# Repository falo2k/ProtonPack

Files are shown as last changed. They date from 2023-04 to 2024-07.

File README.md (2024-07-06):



# Teensy Based Proton Pack Electronics
This is my implementation of the electronics for a Ghostbusters Proton Pack.  It uses a Teensy microcontroller in both parts of the kit (Pack and Wand) and communicates between them over 4 wires (power + serial).  For now I have kept it to a simple movie implementation with some additions - overheating and music playback.  I've added two features that are a bit unusual:
- An OLED display in the rear box on the wand is used for managing volume control and track selection, in conjunctions with a rotary encoder (push/turn) in the front knob.
- A [bluetooth receiver](./Images/bluetooth.jpg) can be turned on for playback of anything not available on the SD card.  The module I'm using will mix the stereo audio down to mono for a single pack, but comes as a pair for True Wireless Stereo.  The other board will be in a friend's pack so we can use the packs as a complete speaker set.
  
It is designed to fit inside the 3D printed pack available [here - the Q-Pack](https://github.com/mr-kiou/q-pack).  It's been developed for a Mk3 pack - I will review it at some point in the future for Mk4 compatability.
  
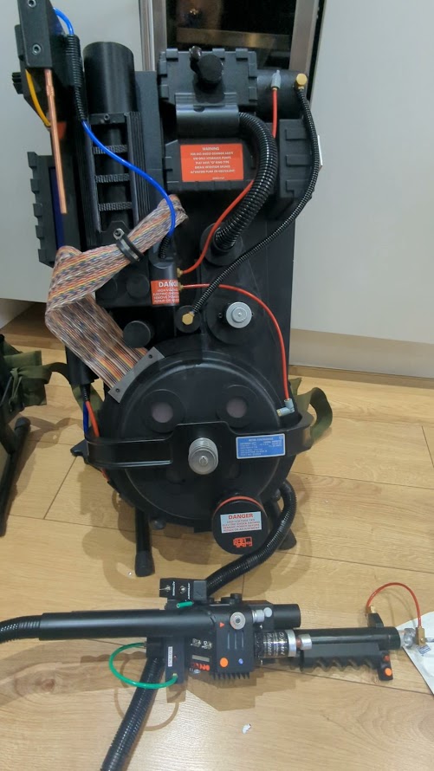
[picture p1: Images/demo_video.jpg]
DEMO VIDEO (https://www.youtube.com/watch?v=gk1BOT_1J4o)
  

## Software
The code is set up as a VS solution/project set using [Visual Micro](https://www.visualmicro.com/), but you can tweak this to your preferred environment.  There are three core files:
- Wand.ino for the Wand sketch on the Teensy LC
- Pack.ino for the Pack sketch on the Teensy 4.0
- ProtonPackCommon.h which is used by both for some shared enums, timers, etc.
  
The Wand sketch does all state management, and will update the Pack sketch as necessary over serial.  If you want to tweak speeds, animations, direction of switches, etc. then you should find the right data to change either above the setup() functions in each file, or within the common header.
  
You'll need the libraries listed in the section below.

### Libraries
[minIni for Arduino](https://github.com/lipoyang/minIni4Arduino) - Config file saving/loading with the SD card  
[LCDGFX](https://github.com/lexus2k/lcdgfx/) - Drives the OLED display  
[CmdMessenger](https://github.com/thijse/Arduino-CmdMessenger) - Manages serial connection between both boards with callbacks  
[Encoder](https://github.com/PaulStoffregen/Encoder) - Converts rotary encoder inputs to movement  
[HT16K33](https://github.com/jonpearse/ht16k33-arduino) - Basic library for controlling the LED matrix backpack/bargraph.  
[NeoPixel](https://github.com/adafruit/Adafruit_NeoPixel) - The Adafruit NeoPixel library.  Considered using FastLED, but as I had GRBW LEDs in stock (and wanted them for some parts) I stuck with the Adafruit library.  
[TimerEvent](https://github.com/cygig/TimerEvent) - A library for managing timing of updates (helping to banish unnecessary delay() calls)  
[Switch](https://github.com/avandalen/avdweb_Switch) - Primarily used for the debouncing and callback features for switches.  Detects events for pressing, holding, and releasing.  

### Pack Operation
Once power is on to both boards, they will start up in the state determined by the current switch positions, so you can switch straight into music mode if you want.  If the pack is powered without a wand connected, it will enter bluetooth mode after 5 seconds.  When both are connected, and the Activate switch is in the off position, a top light on the wand will pulse a faint blue to remind you that your battery is still connected!  

**Act Switch on Left Box**  
- This toggles the pack power-up for both movie and music mode.

**Lower Switch Next to Bargraph**  
- In movie mode this toggles whether or not the overheat warning will kick in after a period of time and then move to venting after further warning.  If off, firing will continue indefinitely.  
- In music mode, this is used to toggle the Bluetooth module on, which will then stop any playback from the SD card.

**Upper Switch Next to Bargraph**  
- This switches between movie mode (off) and music mode (on)

**Int Button on Left Box**  
- In movie mode, this will cause the pack to fire while held.  
- In music mode a single press will act as a play/pause button, while a long press will move to the next track in the list.

**Tip Button**  
- In movie mode, this will cause the pack to fire while held.  If single pressed, it will cause a venting routing to kick off.  
- In music mode a single press will act as a stop button, while a long press will move to the previous track in the list.

**Pack Crank Knob**  
- Connected to an encoder, this independently controls volume of the pack when held and turned.

**Pack Ion Switch**  
- Currently unused.

### OLED Menu System
A long press on the Wand encoder will activate the menu (to avoid accidental bumps).  While active, a long press will also cancel the menu.  The menu has an automatic timeout so will not stay open indefinitely.  Single click to select / confirm menu items

Currently there these features for control:  
1. **Volume**: This changes the volume of the amplifier in the pack via i2c.  This will update as you turn the knob.  
2. **Track Change**: This lets you select the extact track you want queued up for playback from the SD card (if enabled).  Single click to confirm the selection, or long press to cancel.  Selecting a new track while one is playing will cause the new track to start immediately.  Note that using the next/prev track shortcuts on the INT/TIP buttons will display the new track name in the display.  
3. **Overheat/Warning Time**: For overheat mode, this will change the timings for how long until the warning starts (overheat) and how long the warning lasts before forced venting (warning).  
4. **Load/Save Config**: This will load or save the volume, track, and timing configuration to a file on the SD card.  This is loaded as the default when the pack is first powered  
  
A long press in any menu item should take you back up one level.  
  
[Demo video here](https://youtu.be/a6icHuyzO3Q)
  
### Lights Colours & Lenses
The light colours I've used in my code were chosen to work with the lenses and printed hats I'm using.  I would recommend testing against your own installation and tweaking them accordingly.  My setup is:  
- Power cell is a layer of frosted acrylic + a top layer of blue acrylic (so lighting aims to send green and blue only)  
- Cyclotron lenses are just frosted acrylic so I can do any colour.  They are mounted over printed reflectors lined with a red chrome vinyl layer to give them a red tint when off.  
- For the wand LED covers the slo blo is red, tip hat is orange, front shelf is opaque white, top front is clear, and top rear is orange.  

## Music Tracks
I've removed the music tracks from this repository, but you can see which ones I had loaded in [ProtonPackCommon.h](./Teensy/ProtonPackCommon/src/ProtonPackCommon.h).  You can replace these with your own copies, or adapt the header file to manage your own.  I used 16 bit 44.1khz wave files downmixed to mono as I only have a single speaker setup in the pack.  I believe the audio board does support MP3 with some overhead, but there's so much space on a SD card that I didn't care.  Audacity was used for file processing because it's great.  
  
If you want to add more music tracks to the pack, bearing in mind that it might take a while to change them given the simple scrolling menu, then you can update the arrays in ProtonPackCommon.h to reference them.  Make sure to update the track count as well.  
  
### Future Plans
- General code refactoring where I've got a few inconsistent approaches.  Tidy up method signatures a bit to be consistent with ordering of arguments, remove TimerEvent as I've ended up with some custom implementations of the same principle so should be consistent.  
- Some pin headers in the pack are already spare to support adding a smoke machine to the pack at a later date for venting (marked as IO2 on the PCB).  This should be easy to add triggers in software at the appropriate state changes.  I've seen some interesting looking i2c relay boards or i2c IO expanders out there as alternative options if I want more granular control over pump, smoke, fan for the effects.  
- Alternative lighting schemes, sounds, animations, etc. can be added relatively easily.  Switching would probably be done with additional menu items through the OLED controls.  
- I'll play with adding more granular volume control, again through the menu, to individually tweak the volume of SFX, Music, and Bluetooth channels.  This may turn out to be unnnecessary given the sounds should already be balanced and bluetooth volume should be handled by the device sending audio.  
- The Ion Switch input currently doesn't do anything.  I may use this as either a hard or soft toggle for any future smoke effects.  
- Check compatibility with Mk4 Q-Pack and generally review the PCBs for other layout options.  Now I've got my own wiring in, I might see some better positioning for connectors, consider breakout boards, etc.  
- Consider either including an isolated converter in the BOM and as part of existing PCBs, or a breakout depending on power requirements for the smoke system.  
- Reorient the wand board to make the USB port accessible when installed.  At the moment you can't get in there for updates without pulling the Teensy or the whole board.  Neither of those things are fun, and make software updates a pain.  
- Consider a better menu system, and make **all** configurable settings switchable in software.  That would reduce the need for any trial and error with USB cables attached and would allow for all tweaking of things like switch directions, cyclotron spin directions, etc. possible through the OLED menu.  Could even then distribute just the binaries of the firmware for busters who don't want to go anywhere near an IDE.  
- I'd like to add USB panel breakouts onto the motherboard and somewhere on the wand for access to the internal devices without needing to take my shell off.  If I can somehow make the SD card accessible as mass storage when connected as well then so much the better.  

## Hardware
### BOM
Where I can remember it, I've listed the Equipment used and links to purchase below.  You may find other sources are better for availability (Mouser, Digikey, etc.).  As with all of these types of projects, it depends exactly how you're planning to mount your electronics, so I'd advise thinking about your layout before purchasing.  I'm assuming I don't need to go into tools and wire here, that should be a given.  A decent soldering iron is a must, and I have to say how much I'm loving my [Pinecil](https://www.pine64.org/pinecil/), and also the best helping hands I've ever used, the [Omnifixo](https://omnifixo.com/en-gb).  

**Controllers**  
 1 x [Teensy LC](https://www.pjrc.com/store/teensylc.html).  Would be fine using a Teensy 4.0 here as well if availability is a challenge  
 1 x [Teensy 4.0](https://www.pjrc.com/store/teensy40.html)  
 1 x [Teensy Audio Board Rev D](https://www.pjrc.com/store/teensy3_audio.html)  
 1 x [Teensy Stacking Header Kit](https://www.adafruit.com/product/3883).  For the audio board to stack on the Teensy 4.0.  This was the easiest source of 14 pin stackable headers I could find.  If not using PCBs then you may just stick with non-stacking headers here.  
 4 x [14x1R Pins](https://www.pjrc.com/store/header_14x1.html) for the Teensy boards  
 4 x [14x1R Socket Headers](https://www.pjrc.com/store/socket_14x1.html) for the PCBs  
 1 x [5x2R Socket Header](https://www.amazon.co.uk/Double-Female-Straight-Header-Socket-Black/dp/B00R1LKZOM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) for the PCB connection to the audio inputs/outputs on the board  
 1 x Micro SD Card for the Audio Adapter.  See the [Audio Adapter product page](https://www.pjrc.com/store/teensy3_audio.html#:~:text=video%20for%20details.-,Recommended%20SD%20Card,-Most%20SD%20cards) for up to date recommendations.  Not much is stored on here so you can get away with a fairly small card, but if you want to load more songs on YMMV.  

**Premade Boards**  
1 x [Adafruit 16x8 LED Matrix Driver Backpack - HT16K33 Breakout](https://www.adafruit.com/product/1427) for driving the bargraph.  
1 x [DFRobot Mosfet Controller DFR0457](https://wiki.dfrobot.com/Gravity__MOSFET_Power_Controller_SKU__DFR0457) to switch the bluetooth board  
1 x [Adafruit 20W Class D Amplifier](https://www.adafruit.com/product/1752)  
1 x [Bluetooth Audio Board](https://www.aliexpress.com/item/1005004753541997.html). Comes as a wireless stereo pair.  

**Buttons and Switches**  
3 x [2 Position MTS102 mini toggle switches](https://www.amazon.co.uk/gp/product/B01BWL7Z44/) for wand  
1 x [Black Off/On SPST Momentary switch](https://www.amazon.co.uk/gp/product/B00TXNXU4S)  
1 x [Red Off/On SPST Momentary switch](https://www.amazon.co.uk/gp/product/B008ZYE9LY)  
2 x [EC11 Rotary Encoder with Switch](https://www.ebay.co.uk/sch/i.html?_from=R40&_trksid=p2380057.m570.l1313&_nkw=ec11+rotary+encoder&_sacat=0) for the pack (crank) and wand (top / front knob).  Lengths will depend on your shells, and where you're placing the encoder.  
  
Ion switches can be picked up on Etsy.  
  
I also use some of [these](https://www.digikey.co.uk/en/products/detail/e-switch/100DP1T1B1M1QEH/378867) to switch on/off and choose charging vs electronics power for my internally mounted [Talentcell battery](https://talentcell.com/lithium-ion-battery/12v/yb1206000-usb.html).

**LEDs**  
You may want to do your own LEDs.  Numbers and type can be varied in the code, though I haven't allowed for cyclotron LEDs that are more than a single addressable LED in a chain.  You may want to use the 7 LED jewels, though I found they were unnecessary for brightness and just ramped up power consumption for the sake of it.  
1 x [144LEDs/m SK6812 RGBW Strip](https://www.aliexpress.com/item/32476317187.html?spm=a2g0o.order_list.order_list_main.5.74871802yO2AMH).  144 LEDs/m is just enough density to give you 15 LEDs in the Power Cell.  You can get a minimum length if you like.  
13+ x [SK6812 RGBW Chips](https://www.aliexpress.com/item/1005002509850925.html?spm=a2g0o.order_list.order_list_main.29.74871802yO2AMH) which I use in the wand, pack vent, and for the cyclotron.  Worth getting some spares in case you fry one.  
1 x [RGBW LED jewel](https://www.aliexpress.com/item/32825068416.html?spm=a2g0o.order_list.order_list_main.56.74871802yO2AMH) for the barrel light  
1 x [28 Segment Bar Graph](http://www.barmeter.com/download/bl28-3005sx04y.pdf).  Sourcing for this always ends up out of date, so hunt around Aliexpress or try asking on one of the FB groups.  Note that there are two versions of this bargraph, a common anode and common cathode version.  My code is designed for the [BL28-3005SK04Y](./Images/bargraphwiring.jpg) model (note the A or K in the model name differentiating them).  It can be adapted for the other by simply changing the array mapping in the common header to point to the correct row/column references for your model.  

**Capacitors and Resistors**  
4 x 4.7K Ohm Resistors for pullups on the Teensy i2c lines  
6 x 220 Ohm Resistors for neopixel data inputs  
2 x 100 uF Capacitors for neopixel power inputs (these may not be necessary depending on the pixels you're using - I'm keeping them in as they don't harm)  

**Connectors (for PCB / wiring)**  
Source these where you like depending on how many you need / want for other projects.  I tend to buy bulk lots from AliExpress.  You can count up the exact number you need, but I always find I need more so I'll leave them open ended :)  
- [JST-XH connectors and headers](https://www.digikey.co.uk/en/product-highlight/j/jst/xh-series-connectors) for the boards and cables (2,3,4 pin)  
- [Screw terminal blocks](https://www.digikey.co.uk/en/products/detail/phoenix-contact/1729018/260604) (2 pin, 5mm pitch) 
- [Dupont connectors](https://www.amazon.co.uk/dupont-connectors/s?k=dupont+connectors)
- [JST-SM wire to wire connectors](https://www.amazon.co.uk/Aussel-Connector-Housing-Assortment-Kit-560PCS-2-5mm-JST-SM-Connector-560PCS/dp/B0716JMHNJ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) for  (handy locking wire to wire options)  
- [JST-PH connectors](https://www.amazon.co.uk/RUNCCI-YUN-540Pcs-Connector-Housing-Adapter/dp/B092LWQJHN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) (2,3 pin) for some of the smaller connectors on the DFRobot boards and the bluetooth board  
- An assortment of [Wago221s](https://www.amazon.co.uk/s?k=wago+221) because they're brilliant for patching cables together with quick release  
- [2 Pairs of 4 pin aviation connectors](https://www.amazon.co.uk/gp/product/B09WXZNKXN/ref=ppx_yo_dt_b_search_asin_title?ie=UTF8&psc=1) which I use to carry the serial/power to and from the wand while allowing a quick release.

**Other**  
2 x [74AHCT125 Level Shifters](https://www.adafruit.com/product/1787) for driving the Neopixels as the Teensy uses 3.3V logic.  You may get away without these, but better safe than sorry.  
2 x [14 Pin IC Sockets](https://www.digikey.co.uk/en/products/detail/cnc-tech/245-14-1-03/3441580) for mounting the above into the PCBs (or you can just solder them in).  
1 x [0.91-inch OLED Display SSD1306](https://www.amazon.co.uk/gp/product/B07V8B3LSR)
1 x [M6 Thumb Nut](https://www.aliexpress.com/item/1005003320281166.html) for the top knob on the wand.  I drilled out a 2.5 mm hole in the side, tapped it for M3 and used a grub screw to attach it to an encoder.  The top is capped with a cut-off and glued countersunk bolt head.

### PCBs
I have created a couple of PCBs to make installation neater in a Q-Pack.  I've shared the production files in the PCBs folder for use with [JLCPCB](https://jlcpcb.com/).  I used Altium Circuitmaker to create these, so it's hard to share a useful copy of them.  I plan at some point to migrate these to KiCad but that requires time to learn KiCad.  It'll probably happen when I start working on a better belt gizmo :)  
  
The folder also contains STLs to mount the boards and keep the solder joins clear of the mounting surface.  For the Wand, it is just a spacer - the board is designed to fit along the handle side of the Mk3 Q-Pack, using the external M3 bolt to secure it with a nut internally.  This should position the serial/power connections for the handle exit, but leave enough space for an encoder to run through the top/front knob if desired.  For the pack, it's a backer designed to have M3x5x4 heat sets (standard size used in [Vorons](https://www.vorondesign.com/)) added to the holes so the board can be attached and removed easily with M3 bolts.  The backer can then be secured in place to the motherboard with VHB tape.  It should be slim enough to fit underneath the booster box of the Mk3 Q-Pack.  

Lastly, the current version did not take into account the 3mm inset on the box lid.  I have added an alternative STL for this into the folder, but will refactor the PCBs when I redo them in the future.  My STL for the lid also changes some hole sizes as I'm using M3 + heat inserts to attach to the box, and M4 for metal V-Hook/S-Hook connectors.  
  
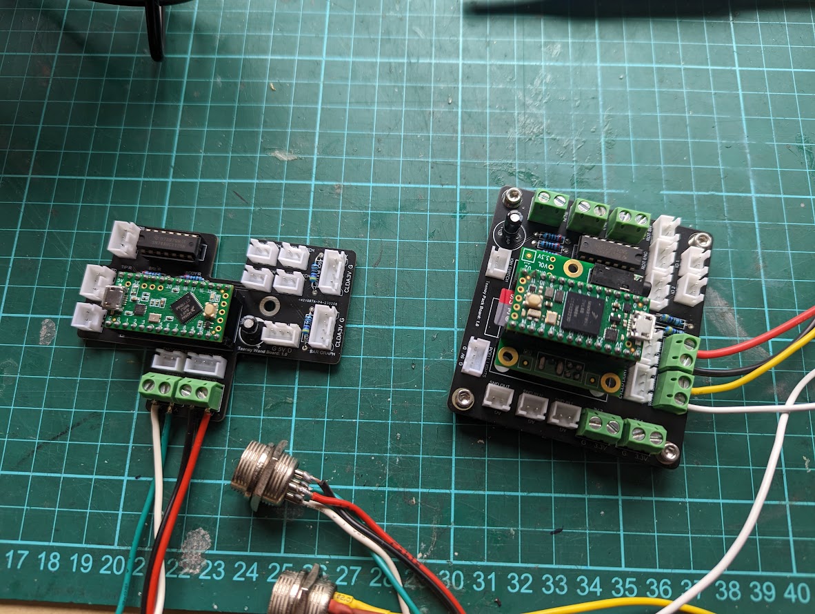
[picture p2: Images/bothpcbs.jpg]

  
*Revision 1.0:* Initial release of boards  
*Revision 1.1:* Pack board updated to move Audio Board output pin.  I made a mis-reading of the schematic, and only the pins nearest the Teensy pins are connected to L/R out.  Temporarily solder bridged on my v1.0 boards.  

### Power
I've left supplying the 5V power to the boards to the individual user.  You can take a feed directly from a Talentcell 5V output or use a common buck converter, but either of these may introduce some noise into the audio.  Your mileage with this may vary.  I got myself some [isolated dc-dc converters](https://www.digikey.co.uk/en/products/detail/mornsun-america-llc/VRB1205S-6WR3/16348304) to step down my 12V talentcell battery and avoid noise issues going to the amp.  6W is overspecced - in my testing, the setup draws at most 0.6A at its busiest time when in the overheat warning sequence.  They're working [well for me so far](./Images/powerboard.jpg).

## Useful Models
I'm slowly going over my library of replacement parts and jigs that I've made over the course of this build and exporting them into the [STLs](./STLs/) folder (and where appropriate I'll feed some back as PRs for the q-pack).  Things like board mounts are generally reusable either with my PCBs or the off-the-shelf boards listed above.  Some bits I've made are very specific to my build so probably not of interest to others.  Have a play with Fusion 360 - you'll both love and hate yourself as a result, but you'll be too far down the rabbit hole of making to notice :)  

If you see any others I'm using in photos and want to get hold of them, let me know.  

## Thanks
A huge thanks to everyone over on the [Arduino for Ghostbusters Props](https://www.facebook.com/groups/1187612118706042/) Facebook group.  Special shout outs to:  
- Chris Rossi for steering me towards the Teensy in the first place
- Kevin Delcourt for his excellent github documentation.  Inspired me to take a different approach to fixing the top knob to the encoder!
- Quentin Machiels and Taco Belli over at [3D Printed Ghostbusters Props](https://www.facebook.com/groups/3DprintedGBprops/), without whom I would not have a pack to build this into
- [Mike Simone](https://github.com/MikeS11/ProtonPack) and [CountDeMonet](https://github.com/CountDeMonet/ArduinoProtonPack) for their implementations.  Both have steered hardware and software choices.

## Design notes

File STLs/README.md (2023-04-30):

Assorted models I've made to make my life easier / support my build.  I will add to this list as I go back and export things.

| File | Description |
| --- | --- |
| [RearBoxOLEDLid](./RearBoxOLEDLid.stl) | A replacement cover for the rear box of the q-pack that fits the OLED display. |
| [PackPCBMount](../PCBs/PackPCBMount.stl) | Mount for my PCB in the pack.  Takes 4 M3x5x4 heat sets. |
| [Wandmount](../PCBs/WandMount.stl) | Spacer to sit behind the wand PCB.  M3 bolt goes through both this and PCB and is secured with a nut. |
| [AmpMount](./AmpMount.stl) | Spacer to hold the Adafruit 20W amp.  Takes [4xM2 heat set inserts](https://www.aliexpress.com/item/1005004535859664.html?spm=a2g0o.order_list.order_list_main.50.54841802o6wcMQ) |
| [BTMount](BTMount.stl) | Plate to screw the DFRobot mosfet board and the bluetooth board down to.  Screw directly into plastic with M3 & M2 bolts. |

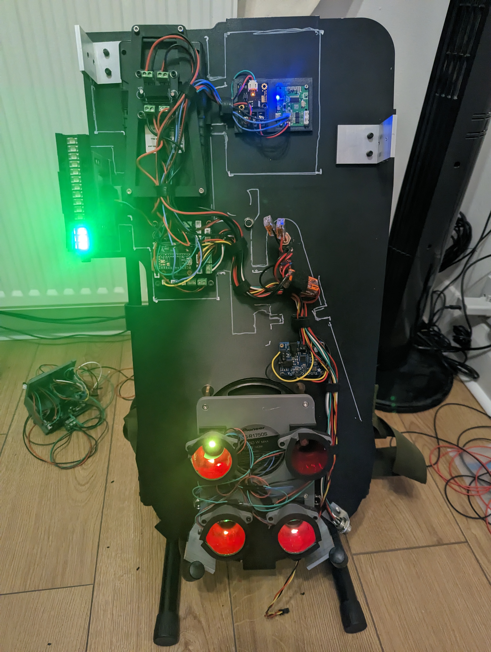
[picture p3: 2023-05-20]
Images/packelectronics.jpg

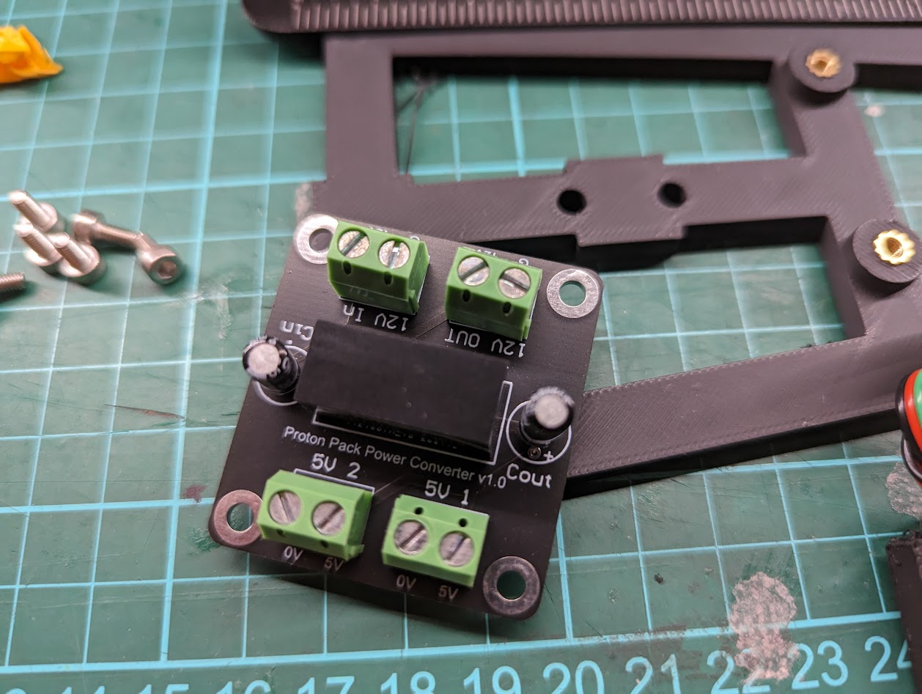
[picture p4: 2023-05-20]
Images/powerboard.jpg

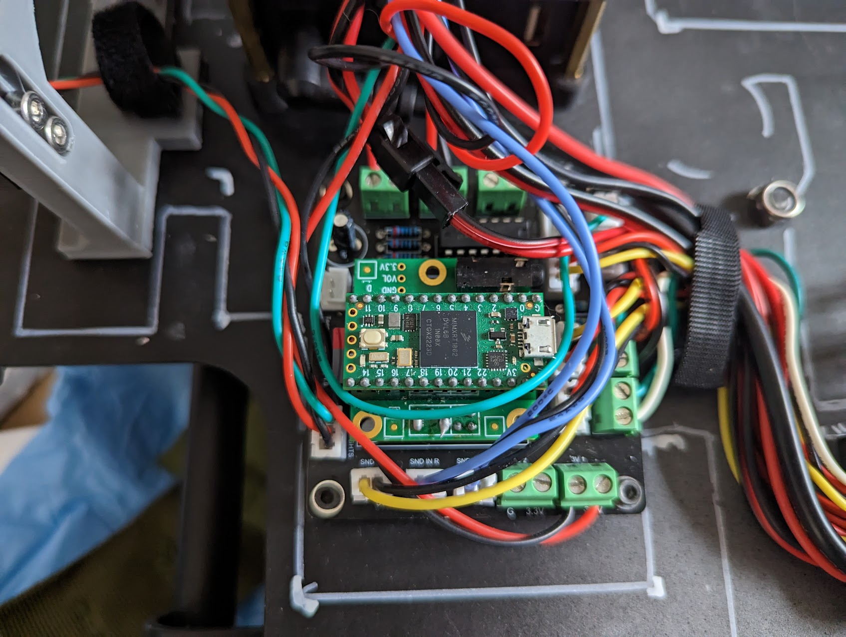
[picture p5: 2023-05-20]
Images/packpcb.jpg

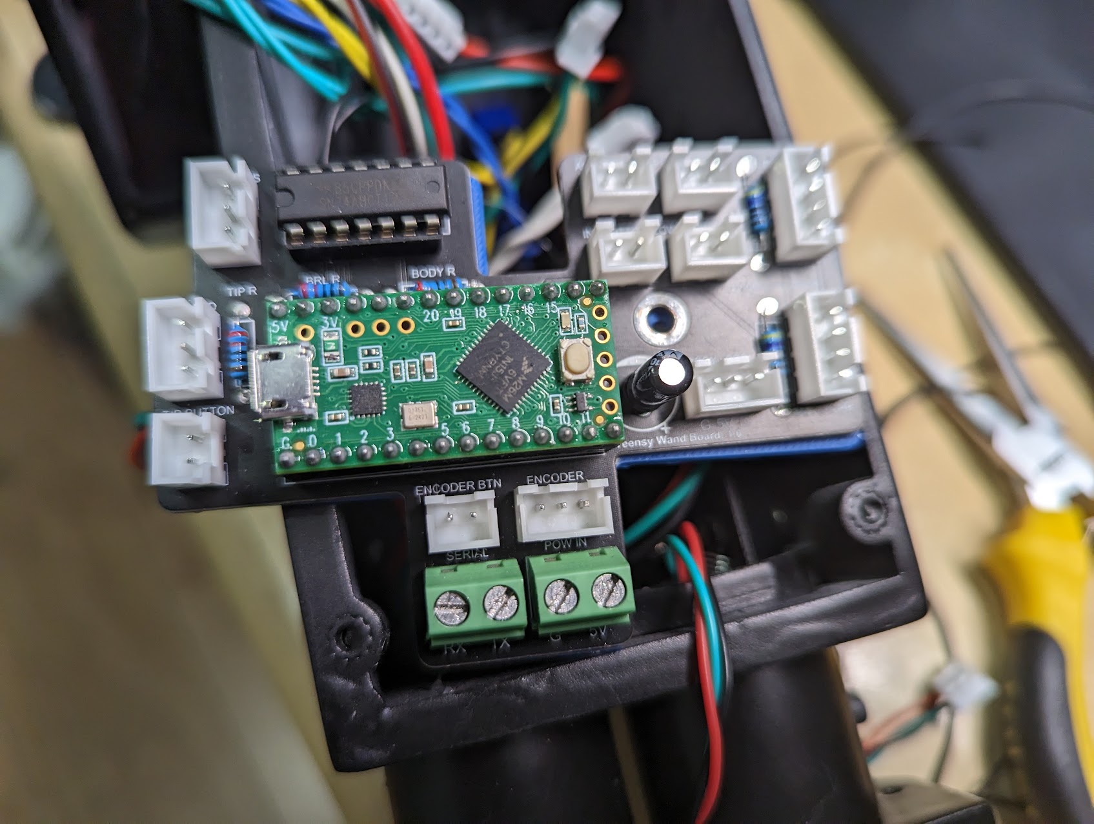
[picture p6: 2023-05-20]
Images/wandpcb.jpg

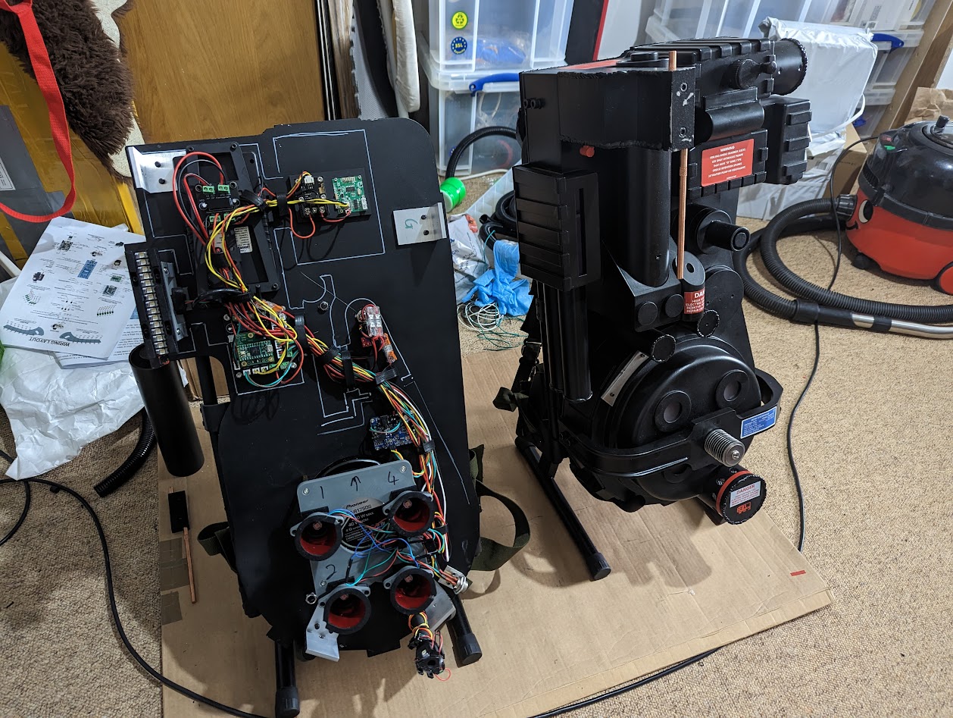
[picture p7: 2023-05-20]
Images/side_by_side.jpg

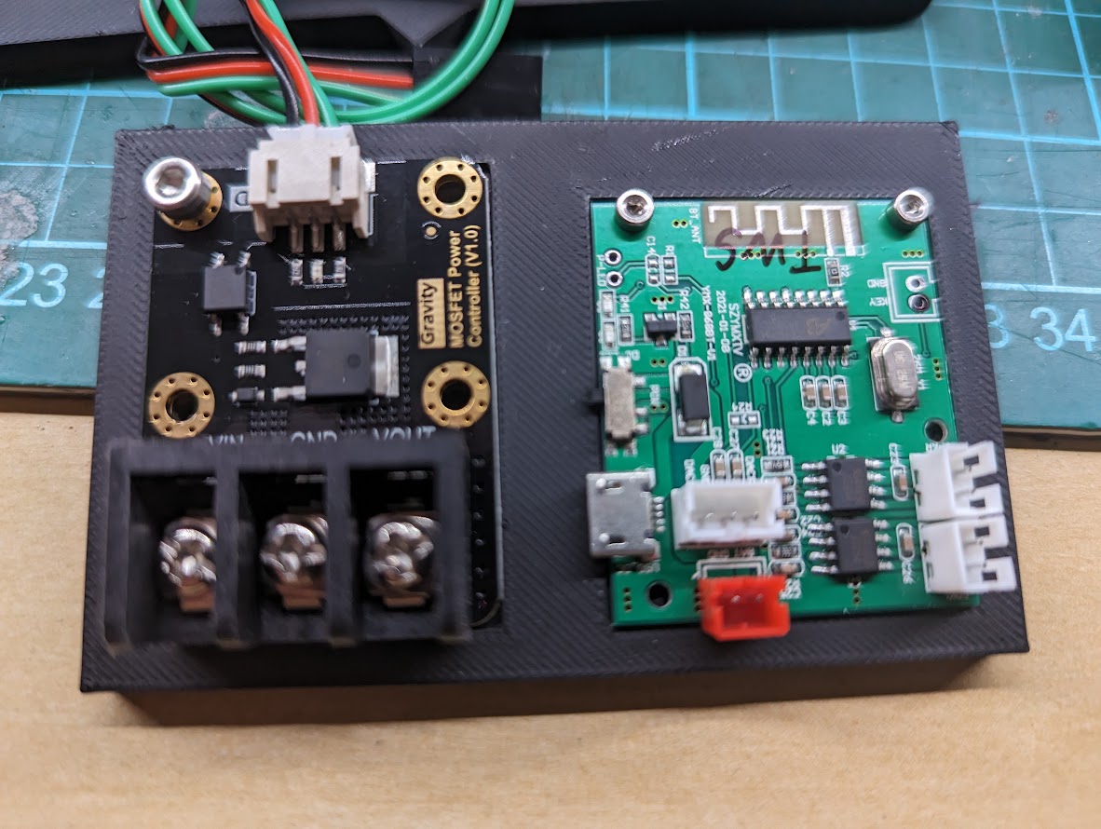
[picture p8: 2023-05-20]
Images/bluetooth.jpg

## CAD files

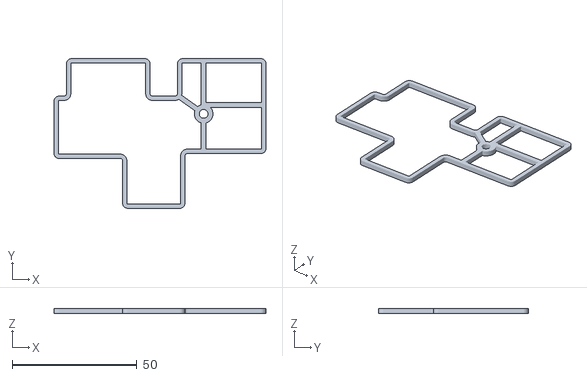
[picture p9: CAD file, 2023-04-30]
PCBs/WandMount.stl
85.0 x 60.0 x 2.00

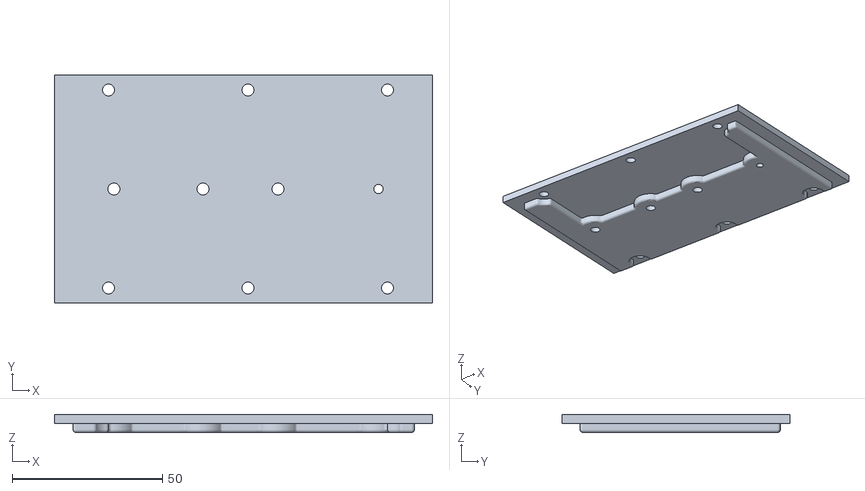
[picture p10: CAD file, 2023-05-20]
STLs/BasePlate.stl
126.0 x 76.0 x 6.00

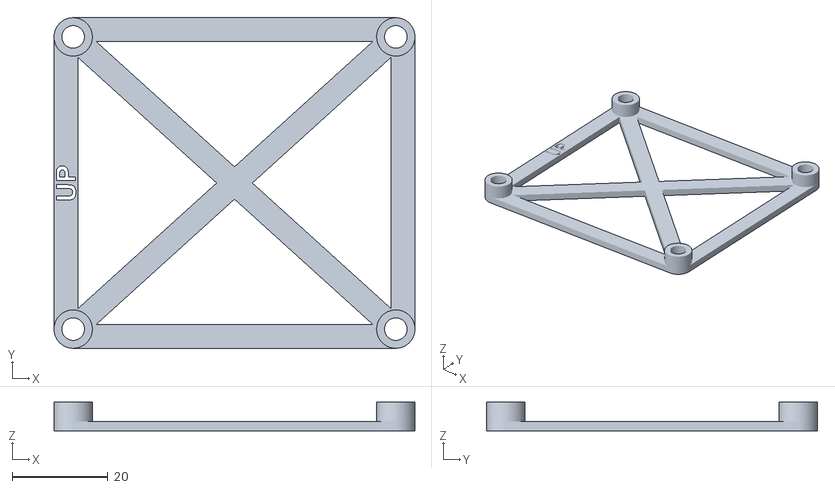
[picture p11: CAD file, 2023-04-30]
PCBs/PackPCBMount.stl
75.3 x 69.0 x 6.00

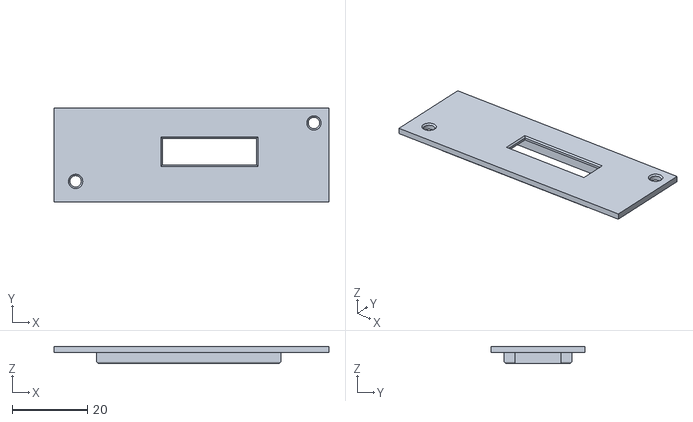
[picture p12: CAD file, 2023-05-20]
STLs/RearBoxOLEDLid.stl
73.0 x 25.0 x 4.60

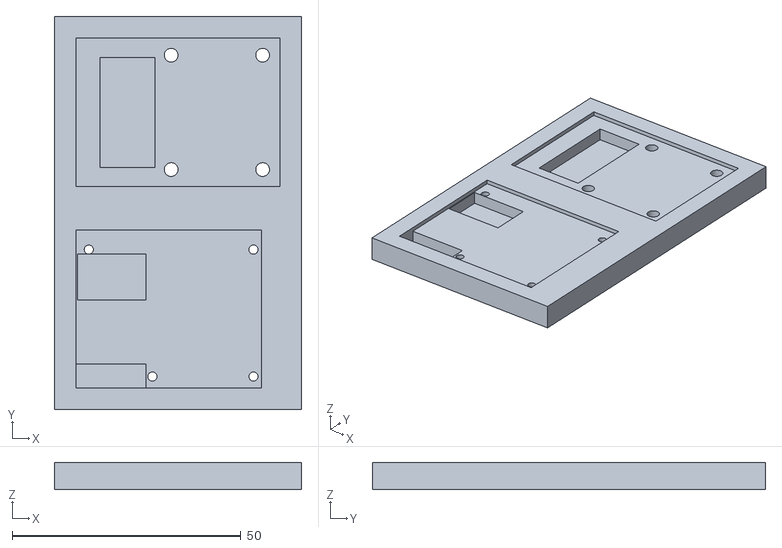
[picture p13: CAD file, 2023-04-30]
STLs/BTMount.stl
54.0 x 86.0 x 6.00

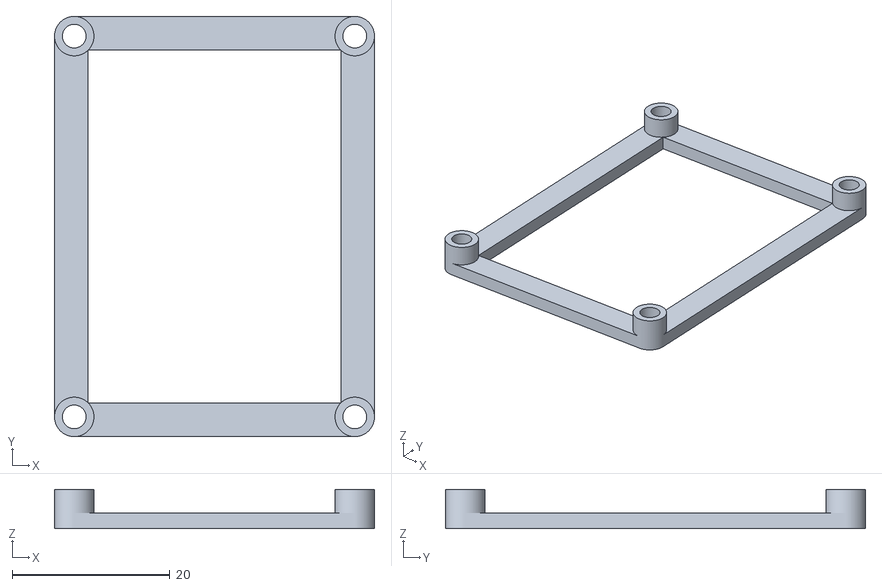
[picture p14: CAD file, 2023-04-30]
STLs/AmpMount.stl
40.6 x 53.3 x 5.00

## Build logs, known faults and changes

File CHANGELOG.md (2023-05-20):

v1.1 First Feedback Tweaks
Some changes made after initial feedback from my cosplay buddy.

- Changed LED colours behind orange hats to not just saturate as red.  Added notes to README.MD regarding changing colours for your own implementation as not everyone has the same LED hat setup.
- The crank knob now acts as an independent volume control (only active when held).  This also works in idle Bluetooth mode for the pack body.
- Fixed idle mode to ensure it loads default volume settings.
- Reduced the maximum "minimum" on the powercell animation to stop it saturating when at full speed (and keep a bit of a blip).
- Due to issues with leaving the pack on and draining battery, added a light blue pulsing colour on the top front LED on the wand.
- Changed the overheat warning and venting on the wand to have the rear top LED flash, and the vent crackle blue.
- Due to the placement of the display and the handle, I modified the back plate to move it over as much as I could while not changing the back box itself.  I also right justified all text so it is easier to see past the wand handle.
- Added customisation options for overheat mode.  The time for both overheat warning starting, and the length of the warning can now be customised.  This can be saved to the SD card.  The default values have been dropped slightly.

v1.0 Initial Release
The first iteration to get some testing for the pack's first outing.  All base features in.

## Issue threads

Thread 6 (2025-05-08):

Error when verifiying wand ino

Tezzuni, 2025-05-08:
Error when verifiying

C:\Users\me\Desktop\ProtonPack-master\Teensy\Wand\Wand.ino:1:1: error: '\U0000feff' does not name a type
    1 |  /*
      |
In file included from c:\Users\me\Documents\Arduino\libraries\ProtonPackCommon\src/ProtonPackCommon.h:6,
                 from C:\Users\me\Desktop\ProtonPack-master\Teensy\Wand\Wand.ino:5:
c:\Users\me\Documents\Arduino\libraries\Adafruit_NeoPixel/Adafruit_NeoPixel.h:229:21: error: 'neoPixelType' has not been declared
  229 |                     neoPixelType type = NEO_GRB + NEO_KHZ800);
      |                     ^~~~~~~~~~~~
c:\Users\me\Documents\Arduino\libraries\Adafruit_NeoPixel/Adafruit_NeoPixel.h:243:19: error: 'neoPixelType' has not been declared
  243 |   void updateType(neoPixelType t);
      |                   ^~~~~~~~~~~~
c:\Users\me\Documents\Arduino\libraries\Adafruit_NeoPixel/Adafruit_NeoPixel.h:383:10: error: 'neoPixelType' does not name a type
  383 |   static neoPixelType str2order(const char *v);
      |          ^~~~~~~~~~~~
C:\Users\me\Desktop\ProtonPack-master\Teensy\Wand\Wand.ino:69:28: error: no matching function for call to 'HT16K33::HT16K33()'
   69 | HT16K33 bargraph = HT16K33();
      |                            ^
In file included from C:\Users\me\Desktop\ProtonPack-master\Teensy\Wand\Wand.ino:15:
c:\Users\me\Documents\Arduino\libraries\HT16K33/HT16K33.h:67:3: note: candidate: 'HT16K33::HT16K33(uint8_t, TwoWire*)'
   67 |   HT16K33(const uint8_t address, TwoWire *wire = &Wire);   //  0x70 .. 0x77
      |   ^~~~~~~
c:\Users\me\Documents\Arduino\libraries\HT16K33/HT16K33.h:67:3: note:   candidate expects 2 arguments, 0 provided
c:\Users\me\Documents\Arduino\libraries\HT16K33/HT16K33.h:64:7: note: candidate: 'constexpr HT16K33::HT16K33(const HT16K33&)'
   64 | class HT16K33
      |       ^~~~~~~
c:\Users\me\Documents\Arduino\libraries\HT16K33/HT16K33.h:64:7: note:   candidate expects 1 argument, 0 provided
c:\Users\me\Documents\Arduino\libraries\HT16K33/HT16K33.h:64:7: note: candidate: 'constexpr HT16K33::HT16K33(HT16K33&&)'
c:\Users\me\Documents\Arduino\libraries\HT16K33/HT16K33.h:64:7: note:   candidate expects 1 argument, 0 provided
C:\Users\me\Desktop\ProtonPack-master\Teensy\Wand\Wand.ino: In function 'void setBGLamp(long unsigned int, int, bool)':
C:\Users\me\Desktop\ProtonPack-master\Teensy\Wand\Wand.ino:277:18: error: 'class HT16K33' has no member named 'setPixel'
  277 |         bargraph.setPixel(bgIndexes[bar-1][0], bgIndexes[bar - 1][1], state ? 1 : 0);
      |                  ^~~~~~~~
C:\Users\me\Desktop\ProtonPack-master\Teensy\Wand\Wand.ino: In function 'void clearBargraph(long unsigned int)':
C:\Users\me\Desktop\ProtonPack-master\Teensy\Wand\Wand.ino:293:18: error: 'class HT16K33' has no member named 'clear'
  293 |         bargraph.clear();
      |                  ^~~~~
C:\Users\me\Desktop\ProtonPack-master\Teensy\Wand\Wand.ino: In function 'void initialiseState(State, long unsigned int)':
C:\Users\me\Desktop\ProtonPack-master\Teensy\Wand\Wand.ino:969:34: error: 'class HT16K33' has no member named 'write'; did you mean 'writeCmd'?
  969 |                         bargraph.write();
      |                                  ^~~~~
      |                                  writeCmd
C:\Users\me\Desktop\ProtonPack-master\Teensy\Wand\Wand.ino:979:34: error: 'class HT16K33' has no member named 'write'; did you mean 'writeCmd'?
  979 |                         bargraph.write();
      |                                  ^~~~~
      |                                  writeCmd
C:\Users\me\Desktop\ProtonPack-master\Teensy\Wand\Wand.ino:998:34: error: 'class HT16K33' has no member named 'write'; did you mean 'writeCmd'?
  998 |                         bargraph.write();
      |                                  ^~~~~
      |                                  writeCmd
C:\Users\me\Desktop\ProtonPack-master\Teensy\Wand\Wand.ino:1044:34: error: 'class HT16K33' has no member named 'write'; did you mean 'writeCmd'?
 1044 |                         bargraph.write();
      |                                  ^~~~~
      |                                  writeCmd
C:\Users\me\Desktop\ProtonPack-master\Teensy\Wand\Wand.ino:1064:34: error: 'class HT16K33' has no member named 'write'; did you mean 'writeCmd'?
 1064 |                         bargraph.write();
      |                                  ^~~~~
      |                                  writeCmd
C:\Users\me\Desktop\ProtonPack-master\Teensy\Wand\Wand.ino: In function 'void graphInit(long unsigned int)':
C:\Users\me\Desktop\ProtonPack-master\Teensy\Wand\Wand.ino:1493:18: error: 'class HT16K33' has no member named 'init'
 1493 |         bargraph.init(0x70);
      |                  ^~~~
C:\Users\me\Desktop\ProtonPack-master\Teensy\Wand\Wand.ino:1498:18: error: 'class HT16K33' has no member named 'write'; did you mean 'writeCmd'?
 1498 |         bargraph.write();
      |                  ^~~~~
      |                  writeCmd
C:\Users\me\Desktop\ProtonPack-master\Teensy\Wand\Wand.ino: In function 'void graphUpdate(long unsigned int)':
C:\Users\me\Desktop\ProtonPack-master\Teensy\Wand\Wand.ino:1513:50: error: 'class HT16K33' has no member named 'write'; did you mean 'writeCmd'?
 1513 |                                         bargraph.write();
      |                                                  ^~~~~
      |                                                  writeCmd
C:\Users\me\Desktop\ProtonPack-master\Teensy\Wand\Wand.ino:1527:42: error: 'class HT16K33' has no member named 'write'; did you mean 'writeCmd'?
 1527 |                                 bargraph.write();
      |                                          ^~~~~
      |                                          writeCmd
C:\Users\me\Desktop\ProtonPack-master\Teensy\Wand\Wand.ino:1542:42: error: 'class HT16K33' has no member named 'write'; did you mean 'writeCmd'?
 1542 |                                 bargraph.write();
      |                                          ^~~~~
      |                                          writeCmd
C:\Users\me\Desktop\ProtonPack-master\Teensy\Wand\Wand.ino:1550:42: error: 'class HT16K33' has no member named 'write'; did you mean 'writeCmd'?
 1550 |                                 bargraph.write();
      |                                          ^~~~~
      |                                          writeCmd
C:\Users\me\Desktop\ProtonPack-master\Teensy\Wand\Wand.ino:1566:42: error: 'class HT16K33' has no member named 'write'; did you mean 'writeCmd'?
 1566 |                                 bargraph.write();
      |                                          ^~~~~
      |                                          writeCmd
C:\Users\me\Desktop\ProtonPack-master\Teensy\Wand\Wand.ino:1579:50: error: 'class HT16K33' has no member named 'write'; did you mean 'writeCmd'?
 1579 |                                         bargraph.write();
      |                                                  ^~~~~
      |                                                  writeCmd
C:\Users\me\Desktop\ProtonPack-master\Teensy\Wand\Wand.ino:1585:42: error: 'class HT16K33' has no member named 'write'; did you mean 'writeCmd'?
 1585 |                                 bargraph.write();
      |                                          ^~~~~
      |                                          writeCmd
Multiple libraries were found for "Adafruit_NeoPixel.h"
  Used: C:\Users\me\Documents\Arduino\libraries\Adafruit_NeoPixel
  Not used: C:\Users\me\AppData\Local\Arduino15\packages\teensy\hardware\avr\1.59.0\libraries\Adafruit_NeoPixel
Multiple libraries were found for "Encoder.h"
  Used: C:\Users\me\Documents\Arduino\libraries\Encoder
  Not used: C:\Users\me\AppData\Local\Arduino15\packages\teensy\hardware\avr\1.59.0\libraries\Encoder
exit status 1

Compilation error: '\U0000feff' does not name a type

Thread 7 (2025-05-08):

Compilation error

Tezzuni, 2025-05-08:
Get the following compilation error even though the file is in Libraries.

C:\Users\me\Desktop\ProtonPack-master\Teensy\Pack\Pack.ino:17:10: fatal error: minINI.h: No such file or directory
   17 | #include <minINI.h>
      |          ^~~~~~~~~~
compilation terminated.
exit status 1

Compilation error: minINI.h: No such file or directory

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

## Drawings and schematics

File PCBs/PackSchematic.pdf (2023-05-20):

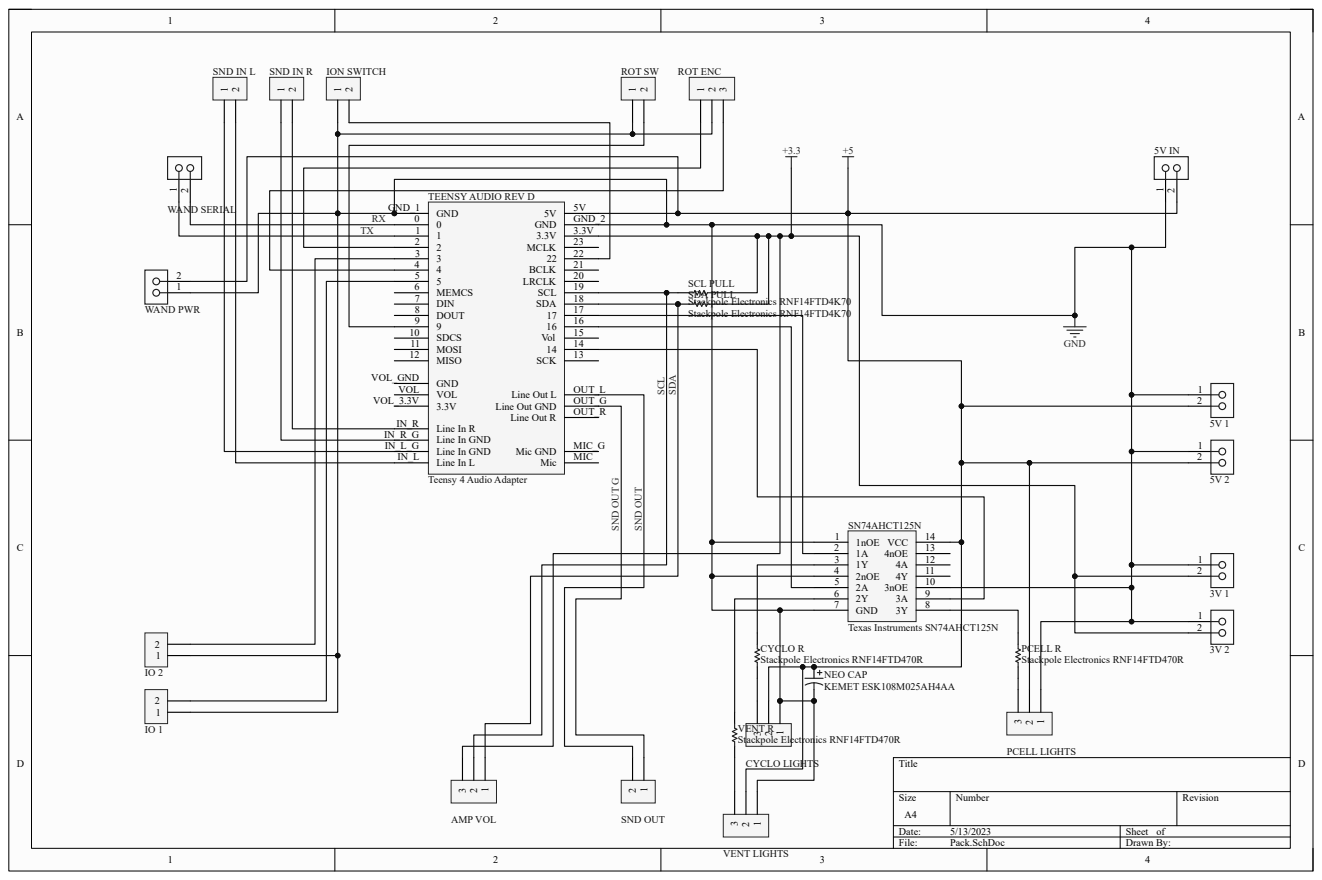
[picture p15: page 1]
Title; Size; Number; Revision; Date:; Sheet of; File:; Pack.SchDoc; Drawn By:; GND; 1nOE 1 1A 2 1Y 3 2nOE 4 2A 5 2Y 6 GND 7; VCC; 4nOE; 3nOE; SN74AHCT125N; Texas Instruments SN74AHCT125N; CYCLO LIGHTS; ION SWITCH; 2 WAND SERIAL; NEO CAP KEMET ESK108M025AH4AA; ROT SW; ROT ENC; CYCLO R Stackpole Electronics RNF14FTD470R; WAND PWR; SND IN L; SND IN R; SCL SDA SND OUT G; SND OUT; 1 SND OUT ³ 2; AMP VOL; VENT LIGHTS; VENT R; Stackpole Electronics RNF14FTD470R; PCELL LIGHTS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

TEENSY AUDIO REV D

SCL PULL
Stackpole Electronics RNF14FTD4K70 SDA PULL
Stackpole Electronics RNF14FTD4K70

Line In R IN_R
Line In GND IN_R_G
Line In GND IN_L_G
Line In L IN_L

Teensy 4 Audio Adapter

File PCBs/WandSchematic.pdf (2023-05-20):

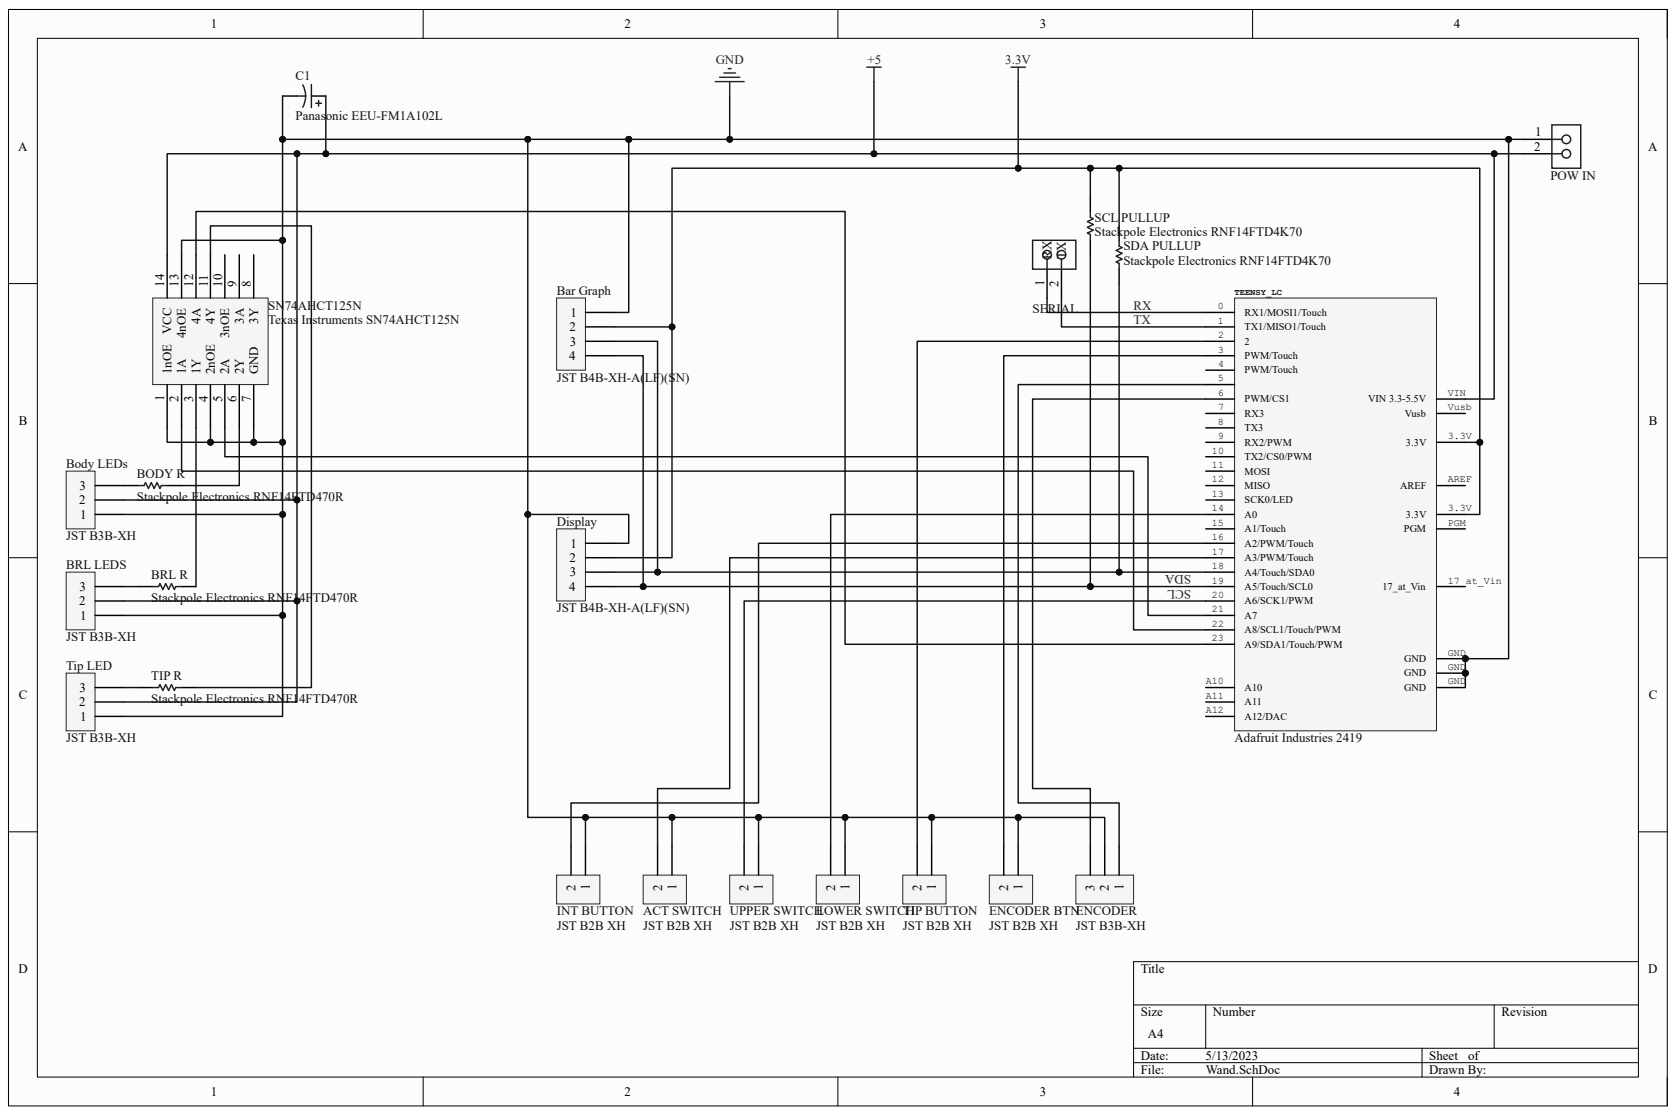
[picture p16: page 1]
Title; Size; Number; Revision; Date:; Sheet of; File:; Wand.SchDoc; Drawn By: ¹nOE; 3 2nOE; 6 GND; 7 VCC 14 4nOE 13 4A 12 4Y 11 3nOE 10 3A 9 3Y; SN74AHCT125N Texas Instruments SN74AHCT125N; Body LEDs; JST B3B-XH; 2 SERIAL; 1 INT BUTTON JST B2B XH; MISO 12; MOSI 11; TX2/CS0/PWM 10; RX2/PWM 9; PWM/CS1 6; PWM/Touch 4; PWM/Touch 3; TX1/MISO1/Touch 1; RX1/MOSI1/Touch 0; GND; VIN 3.3-5.5V; VIN; A9/SDA1/Touch/PWM 23; A8/SCL1/Touch/PWM 22; A6/SCK1/PWM 20; A5/Touch/SCL0 19; A4/Touch/SDA0 18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

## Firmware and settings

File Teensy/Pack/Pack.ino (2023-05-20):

/*
 This sketch is designed to run on a Teensy 4.0 / Audio Board in the proton pack.
*/

#include <ProtonPackCommon.h>

#include <Audio.h>
#include <Wire.h>
#include <SPI.h>
#include <SD.h>
#include <SerialFlash.h>
#include <Adafruit_NeoPixel.h>
#include <TimerEvent.h>
#include <CmdMessenger.h>
#include <avdweb_Switch.h>
#include <Encoder.h>
#include <minINI.h>

/*  ----------------------
    Variables to flip switch directions depending on
    your wiring implementation
----------------------- */
int rotaryDirection = 1;
const bool SW_ION_INVERT = false;
int cyclotronDirection = 1;

/*  ----------------------
    Pin & Range Definitions
    : Note that for ranges the indexes are inclusive
----------------------- */
// Switches
const int ION_SWITCH_PIN = 22;
const int ROT_BTN_PIN = 9;
const int ROT_ENC_A_PIN = 4;
const int ROT_ENC_B_PIN = 2;

const int IO_1_PIN = 5;
const int IO_2_PIN = 3;

// LEDs
const int PCELL_LED_PIN = 14;
const int CYCLO_LED_PIN = 17;
const int VENT_LED_PIN = 16;

const int PCELL_LED_COUNT = 15;
const int CYCLO_LED_COUNT = 4;
const int VENT_LED_COUNT = 3;

/*  ----------------------
    Library objects
----------------------- */
// Audio System
#define mixerChannel1 0
#define mixerChannel2 1
#define mixerAudioInChannel 2

// GUItool: begin automatically generated code
AudioInputI2S            audioIn;           //xy=303,455
AudioPlaySdWav           sdBackgroundChannel;     //xy=326,249
AudioPlaySdWav           sdFXChannel; //xy=328,337
AudioMixer4              audioInMonoMix;         //xy=517,455
AudioMixer4              audioMixer;         //xy=728,389
AudioOutputI2S           audioOutput;           //xy=930,414
AudioAnalyzeRMS          audioRMS;           //xy=913,594
AudioAnalyzePeak         audioPeak;          //xy=916,517
AudioAnalyzeFFT256       audioFFT;
AudioConnection          patchCord1(audioIn, 0, audioInMonoMix, 0);
AudioConnection          patchCord2(audioIn, 1, audioInMonoMix, 1);
AudioConnection          patchCord3(sdBackgroundChannel, 0, audioMixer, mixerChannel1);
AudioConnection          patchCord4(sdFXChannel, 0, audioMixer, mixerChannel2);
AudioConnection          patchCord5(audioInMonoMix, 0, audioMixer, mixerAudioInChannel);
AudioConnection          patchCord6(audioMixer, 0, audioOutput, 0);
AudioConnection          patchCord7(audioMixer, audioPeak);
AudioConnection          patchCord8(audioMixer, audioRMS);
AudioConnection          patchCord9(audioMixer, audioFFT);
AudioControlSGTL5000     sgtl5000_1;     //xy=625,590
// GUItool: end automatically generated code

#define SDCARD_CS_PIN    10
#define SDCARD_MOSI_PIN  7
#define SDCARD_SCK_PIN   14

// Amplifier
#define MAX9744_I2CADDR 0x4B

// Neopixels
Adafruit_NeoPixel pcellLights = Adafruit_NeoPixel(PCELL_LED_COUNT, PCELL_LED_PIN, NEO_GRBW + NEO_KHZ800);
Adafruit_NeoPixel cycloLights = Adafruit_NeoPixel(CYCLO_LED_COUNT, CYCLO_LED_PIN, NEO_GRBW + NEO_KHZ800);
Adafruit_NeoPixel ventLights = Adafruit_NeoPixel(VENT_LED_COUNT, VENT_LED_PIN, NEO_GRBW + NEO_KHZ800);

// Serial Comms to Wand
CmdMessenger cmdMessenger = CmdMessenger(Serial1);

// Switches and buttons
Encoder ROTARY(ROT_ENC_A_PIN, ROT_ENC_B_PIN);
Switch ionSwitch = Switch(ION_SWITCH_PIN);
Switch encoderButton = Switch(ROT_BTN_PIN);

/*  ----------------------
    Timers
----------------------- */
TimerEvent pcellTimer;
int pcellTimerPeriod = 50;
TimerEvent cycloTimer;
int cycloTimerPeriod = 50;
TimerEvent ventTimer;
int ventTimerPeriod = 50;

/*  ----------------------
    State control
----------------------- */
State state = OFF;

int lastRotaryPosition = 0;
bool bluetoothMode = false;
int trackNumber = defaultTrack;
unsigned long stateLastChanged;

bool wandConnected = false;

// POWER CELL STATE
int powerCellLitBar = 0;
const int powerCellIdlePeriod = 1000;
const int powerCellFiringPeriod = 500;
int powerCellPeriod = 1000;
const int powerDownPCellDecayTickPeriod = (int)(0.025 * POWERDOWN_TIME);
unsigned long lastPowerCellChange;
const uint32_t pCellColour = Adafruit_NeoPixel::Color(150, 150, 250);
float pCellMinBar = 0.0;
float pCellMaxMinBar = 12;
// Rate for power cell minimum to climb when firing
const int pCellClimbPeriod = 500;
const float pCellClimbRate = 1.0 / pCellClimbPeriod;
const float peakMultiplier = 2;

// CYCLOTRON STATE
int cyclotronLitIndex = 0;
unsigned long lastCycloChange[CYCLO_LED_COUNT];
const int cyclotronMinPeriod = 100;
const int cyclotronIdlePeriod = 4000;
// ms to reduce spin period per ms of firing
const float cyclotronFiringAcceleration = 0.01;
int cyclotronSpinPeriod = 4000;
// Rate for cyclotron lamps to fade under normal operation
const int lampFadeMs = 250;
const float cycloSpinDecayRate = 255.0 / lampFadeMs;

// Scaling used for audio visualisation
const float fftMultiplier = 2;
const float fftExponent = 0.5;
const float fftThreshold = 0.02;
const float rmsMultiplier = 4;
const float rmsExponent = 1;

uint32_t savedCyclotronValues[CYCLO_LED_COUNT];

//const unsigned long powerDownCycloDecayTickPeriod = (int)(0.1 * POWERDOWN_TIME);
// Decay rate for powercell shutdown in pixel value per ms.  
// At most full lights switch off in 80% of shutdown time
const float powerDownCycloDecayRate = (float)255 / (0.8 * POWERDOWN_TIME);

uint32_t cyclotronFull = Adafruit_NeoPixel::Color(255, 0, 0, 0);
uint32_t cyclotronOverheat = Adafruit_NeoPixel::Color(255, 0, 0, 10);
uint32_t ventColour = Adafruit_NeoPixel::Color(255, 255, 255, 255);

// Time out and enter demo mode (music mode with bluetooth) if
// it's been 5s since booting and no sign of the wand
unsigned long bootTime;
const unsigned long wandTimeoutTime = 5000;

/*  ----------------------
    Setup and Loops
----------------------- */
void setup() {
    // Initialise Serial for Debug + Wand Connection
    Serial.begin(9600);
    Serial1.begin(9600);

    DEBUG_SERIAL.println("Starting Setup");

    // Enable Wand Serial Comms
    DEBUG_SERIAL.println("Setting up Serial port");
    cmdMessenger.printLfCr();
    attachCmdMessengerCallbacks();
    DEBUG_SERIAL.println("Serial Setup Complete");

    // Set up the amplifier
    Wire.begin();
    // This should now happen in the first call to load the config file
    //if (!setvolume(theVol)) {
    //    DEBUG_SERIAL.println("Failed to set volume, MAX9744 not found!");
    //    // Should loop here until ready - or loop for a small amount of time?
    //    // // Error message over serial to display?
    //    //while (1);
    //}
    
    // Initialise the audio board
    // Audio connections require memory to work.  For more
    // detailed information, see the MemoryAndCpuUsage example
    AudioMemory(24);
    sgtl5000_1.enable();
    sgtl5000_1.volume(0.75);
    sgtl5000_1.inputSelect(AUDIO_INPUT_LINEIN);
    audioFFT.averageTogether(10);
    //audioFFT.windowFunction(NULL);

    // Ensure the mono-mixer maxes out at 1
    audioInMonoMix.gain(0, 0.5);
    audioInMonoMix.gain(1, 0.5);

    // Set up the balance of gains initially for two channel FX/MUSIC
    audioMixer.gain(mixerChannel1, 0.5);
    audioMixer.gain(mixerChannel2, 0.5);
    audioMixer.gain(mixerAudioInChannel, 0.0);

    SPI.setMOSI(SDCARD_MOSI_PIN);
    SPI.setSCK(SDCARD_SCK_PIN);
    if (!(SD.begin(SDCARD_CS_PIN))) {
        // stop here, but print a message repetitively
        while (1) {
            DEBUG_SERIAL.println("Unable to access the SD card");
            delay(500);
       }
    }

    // Initialise LEDs and Timers
    pcellLights.begin();
    cycloLights.begin();
    ventLights.begin();
    
    cycloLights.clear();
    ventLights.clear();
    
    pcellInit();
    pcellTimer.set(pcellTimerPeriod, pcellUpdate);
    cycloInit();
    cycloTimer.set(cycloTimerPeriod, cycloUpdate);
    ventInit();
    ventTimer.set(ventTimerPeriod, ventUpdate);

    pcellLights.show();
    cycloLights.show();
    ventLights.show();

    // Initiate the input switches
    setupInputs();

    // Set up output pins
    pinMode(IO_1_PIN, OUTPUT); // Bluetooth control
    digitalWrite(IO_1_PIN, LOW);

    bootTime = millis();
    DEBUG_SERIAL.println("setup() Complete");
}

// Tracker time to space out checks for wand connection
unsigned long lastWandCheck = millis();

void loop() {
    unsigned long currentMillis = millis();

    if (!wandConnected) {
        if (((currentMillis - lastWandCheck) > 250)) {
            DEBUG_SERIAL.println("Pack waiting for Wand ...");
            cmdMessenger.sendCmd(eventPackConnect);
            lastWandCheck = currentMillis;
        }
        cmdMessenger.feedinSerialData();

        // If we timeout turn on music mode and bluetooth
        // Pretend the wand is connected
        // Otherwise keep waiting
        if ((currentMillis - bootTime) > wandTimeoutTime) {
            DEBUG_SERIAL.println("Waiting for wand timed out.  Enabling demo mode.");
            wandConnected = true;

            readConfigFile(currentMillis);
            setvolume(theVol);

            initialiseState(MUSIC_MODE, currentMillis);
            bluetoothMode = true;
            toggleBluetoothModule(bluetoothMode);
        }
        else {
            return;
        }        
    }

    // Process State Updates
    stateUpdate(currentMillis);

    // Get any updates from wand
    cmdMessenger.feedinSerialData();

    // Process Switch Updates
    updateInputs(currentMillis);    

    // Process LED Updates
    pcellTimer.update();
    cycloTimer.update();
    ventTimer.update();
}

/*  ----------------------
    Config Management
----------------------- */
void readConfigFile(unsigned long currentMillis) {
    if (SD.exists(configFile)) {
        DEBUG_SERIAL.println("Config File Found.  Reading Config.");
        minIni ini(configFile);
        theVol = ini.geti("", configVolume, defaultVol);
        trackNumber = ini.geti("", configTrack, defaultTrack);
        OVERHEAT_TIME = ini.geti("", configOverheat, OVERHEAT_DEFAULT_TIME);
        FIRING_WARN_TIME = ini.geti("", configWarn, FIRING_WARN_DEFAULT_TIME);
    }
    else {
        DEBUG_SERIAL.println("No Config File Found.  Using Default values.");
        trackNumber = defaultTrack;
        theVol = defaultVol;
        OVERHEAT_TIME = OVERHEAT_DEFAULT_TIME;
        FIRING_WARN_TIME = FIRING_WARN_DEFAULT_TIME;
    }
}

void writeConfigFile(unsigned long currentMillis) {
    DEBUG_SERIAL.println("Saving config file to SD.");
    
    minIni ini(configFile);

    ini.put("", configVolume, theVol);
    ini.put("", configTrack, trackNumber);
    ini.put("", configOverheat, OVERHEAT_TIME);
    ini.put("", configWarn, FIRING_WARN_TIME);
}

/*  ----------------------
    Input Management
----------------------- */
void setupInputs() {
    ionSwitch.setPushedCallback(&ionSwitchToggle);
    ionSwitch.setReleasedCallback(&ionSwitchToggle);
    encoderButton.setPushedCallback(&rotaryButtonPress);
    encoderButton.setReleasedCallback(&rotaryButtonRelease);
    encoderButton.setLongPressCallback(&rotaryButtonLongPress);
}

void updateInputs(unsigned long currentMillis) {
    // Handle Switches
    ionSwitch.poll();
    encoderButton.poll();

    // Handle Rotary Encoder Movements
    int newRotaryPosition = ROTARY.read();
    if (abs(newRotaryPosition - lastRotaryPosition) >= 4) {
        DEBUG_SERIAL.print("Rotary Position: "); DEBUG_SERIAL.println(newRotaryPosition);
        int movement = rotaryDirection * round(0.25 * (newRotaryPosition - lastRotaryPosition));
        lastRotaryPosition = newRotaryPosition;

        DEBUG_SERIAL.print("Rotary Movement: "); DEBUG_SERIAL.println(movement);

        rotaryMove(currentMillis, movement);
    }
}

void ionSwitchToggle(void* ref) {
    DEBUG_SERIAL.print("Ion Switch: "); DEBUG_SERIAL.println(ionSwitch.on() ^ SW_ION_INVERT);

    cmdMessenger.sendCmd(eventPackIonSwitch, ionSwitch.on() ^ SW_ION_INVERT);
}

bool encoderHeld = false;
bool encoderPressed = false;

void rotaryButtonPress(void* ref) {
    DEBUG_SERIAL.println("Rotary Pressed");
    encoderPressed = true;
    //cmdMessenger.sendCmd(eventPackEncoderButton, PRESSED);
}

void rotaryButtonLongPress(void* ref) {
    DEBUG_SERIAL.println("Rotary Held");
    encoderHeld = true;
    //cmdMessenger.sendCmd(eventPackEncoderButton, HELD);    
}

void rotaryButtonRelease(void* ref) {
    // Encoder is bouncing weirdly on startup.  Ingore if it wasn't pressed in the first place.
    if (!encoderPressed) { return; }
    else {
        encoderPressed = false;
    }

    DEBUG_SERIAL.println("Rotary Released");

    if (encoderHeld) {
        encoderHeld = false;
    }

    //cmdMessenger.sendCmd(eventPackEncoderButton, RELEASED);
}

void rotaryMove(unsigned long currentMillis, int movement) {
    // Change the volume only if held and moved
    if (encoderHeld) {
        setvolume(theVol + movement);
        cmdMessenger.sendCmd(eventSetVolume, theVol);
        cmdMessenger.sendCmd(eventDisplayVolume, theVol);
    }
    //cmdMessenger.sendCmd(eventPackEncoderTurn, movement);
}

/*  ----------------------
    Music Functions
----------------------- */
void playRandomTrack() {
    if (sdFXChannel.isPlaying()) {
        sdFXChannel.stop();
    }

    sdFXChannel.play(trackList[random(0, 6)][0]);
    delay(10);
}

// Setting the volume is very simple! Just write the 6-bit
// volume to the i2c bus. That's it!
boolean setvolume(int8_t v) {
    // cant be higher than 63 or lower than 0
    if (v > maxVol) v = maxVol;
    if (v < 0) v = 0;

    if (v != theVol) {
        DEBUG_SERIAL.printf("Setting volume to %i\n", v);
    }

    theVol = v;

    Wire.beginTransmission(MAX9744_I2CADDR);
    Wire.write(v);
    if (Wire.endTransmission() == 0) {        
        return true;
    }
    else {
        return false;
    }
}

void toggleBluetoothModule(bool state) {
    DEBUG_SERIAL.print("Switching Bluetooth Module: "); DEBUG_SERIAL.println(state);

    if (state) {
        sdFXChannel.stop();
        audioMixer.gain(mixerChannel2, 0.0);
        audioMixer.gain(mixerAudioInChannel, 0.5);
        digitalWrite(IO_1_PIN, HIGH);
    }
    else {
        audioMixer.gain(mixerChannel2, 0.5);
        audioMixer.gain(mixerAudioInChannel, 0.0);
        digitalWrite(IO_1_PIN, LOW);
    }
}

/*  ----------------------
    Serial Command Handling
----------------------- */
// Handle these: 
//eventSetVolume,
//eventChangeState,
//eventSetBluetoothMode,
//eventSetSDTrack,
//eventPlayPauseSDTrack,
//eventStopSDTrack,

void attachCmdMessengerCallbacks() {
    cmdMessenger.attach(onUnknownCommand);
    cmdMessenger.attach(eventSetVolume, onSetVolume);
    cmdMessenger.attach(eventChangeState, onChangeState);
    cmdMessenger.attach(eventSetBluetoothMode, onSetBluetoothMode);
    cmdMessenger.attach(eventSetSDTrack, onSetSDTrack);
    cmdMessenger.attach(eventPlayPauseSDTrack, onPlayPauseSDTrack);
    cmdMessenger.attach(eventStopSDTrack, onStopSDTrack);
    cmdMessenger.attach(eventLoadConfig, onLoadConfig);
    cmdMessenger.attach(eventWriteConfig, onWriteConfig);
    cmdMessenger.attach(eventWandConnect, onWandConnect);
    cmdMessenger.attach(eventSendConfigToPack, onSendConfigToPack);
}

void onUnknownCommand()
{
    DEBUG_SERIAL.println("Command without attached callback");
}

void onSetVolume() {
    theVol = cmdMessenger.readInt16Arg();
    setvolume(theVol);
}

void onChangeState() {
    State newState = (State)cmdMessenger.readInt16Arg();
    initialiseState(newState, millis());
}

void onSetBluetoothMode() {
    bool arg = cmdMessenger.readBoolArg();
    
    bluetoothMode = arg;

    if (state == MUSIC_MODE) {
        toggleBluetoothModule(bluetoothMode);
    }
}

void onSetSDTrack() {
    int newTrackNumber = cmdMessenger.readInt16Arg();

    if (newTrackNumber != trackNumber) {
        DEBUG_SERIAL.printf("Setting Track to %s\n", trackList[newTrackNumber][1]);
        trackNumber = newTrackNumber;

        if (sdFXChannel.isPlaying() || sdFXChannel.isPaused()) {
            sdFXChannel.stop();
            sdFXChannel.play(trackList[trackNumber][0]);
        }
    }
}

void onPlayPauseSDTrack() {
    if ((state == MUSIC_MODE) && !bluetoothMode) {
        if (sdFXChannel.isPaused()) {
            sdFXChannel.togglePlayPause();
        }
        else if (sdFXChannel.isPlaying()) {
            sdFXChannel.togglePlayPause();
        }
        else {
            sdFXChannel.play(trackList[trackNumber][0]);
        }
    }
}

void onStopSDTrack() {
    if ((state == MUSIC_MODE) && !bluetoothMode) {
        sdFXChannel.stop();
    }
}

void onLoadConfig() {
    readConfigFile(millis());
    cmdMessenger.sendCmd(eventSetVolume, theVol);
    cmdMessenger.sendCmd(eventSetSDTrack, trackNumber);
    cmdMessenger.sendCmdStart(eventSendConfigToWand);
    cmdMessenger.sendCmdArg(OVERHEAT_TIME);
    cmdMessenger.sendCmdArg(FIRING_WARN_TIME);
    cmdMessenger.sendCmdEnd();
}

void onWriteConfig() {
    writeConfigFile(millis());
}

void onSendConfigToPack() {
    DEBUG_SERIAL.println("Received configuration from wand");
    OVERHEAT_TIME = cmdMessenger.readInt16Arg();
    FIRING_WARN_TIME = cmdMessenger.readInt16Arg();
}

// Wand Connect - Send acknowledgment
void onWandConnect() {
    DEBUG_SERIAL.println("Wand Connected");
    wandConnected = true;
    cmdMessenger.sendCmd(eventPackConnect);
}

/*  ----------------------
    State Management
----------------------- */
void initialiseState(State newState, unsigned long currentMillis) {
    DEBUG_SERIAL.print("Initialising State: "); DEBUG_SERIAL.println((char)newState);

    // Ensure we stop the music if we're coming from music mode,
    // and make sure bluetooth module is shut down
    if (state == MUSIC_MODE && newState != MUSIC_MODE) {
        sdFXChannel.stop();
        toggleBluetoothModule(false);
    }

    switch (newState) {
    case OFF:
        pcellLights.clear();
        cycloLights.clear();
        ventLights.clear();
        sdBackgroundChannel.stop();
        sdFXChannel.stop();
        toggleBluetoothModule(false);
        break;

    case BOOTING:
        // Start from all lights off
        pcellLights.clear();
        cycloLights.clear();
        ventLights.clear();
        sdBackgroundChannel.stop();
        sdFXChannel.play(sfxBoot);
        break;

    case IDLE:
        powerCellPeriod = powerCellIdlePeriod;
        cyclotronSpinPeriod = cyclotronIdlePeriod;        
        pCellMinBar = 0.0;
        pcellLights.clear();
        ventLights.clear();

        // Store current cyclotron value state for bulb fade - at this point
        // I'm wondering if I should just cache these on any change, but here we are
        for (int i = 0; i < CYCLO_LED_COUNT; i++) {
            savedCyclotronValues[i] = cycloLights.getPixelColor(i);
        }

        break;

    case POWERDOWN:
        for (int i = 0; i < CYCLO_LED_COUNT; i++) {
            savedCyclotronValues[i] = cycloLights.getPixelColor(i);
        }

        sdBackgroundChannel.stop();
        sdFXChannel.play(sfxPowerDown);
        break;

    case FIRING:
        pCellMinBar = 0.0;// 0.1 * PCELL_LED_COUNT;
        powerCellPeriod = powerCellFiringPeriod;

        sdFXChannel.play(sfxFireHead);
        sdBackgroundChannel.play(sfxFireLoop);
        break;

    case FIRING_STOP:
        sdBackgroundChannel.stop();
        sdBackgroundChannel.play(sfxHum);
        sdFXChannel.play(sfxFireTail);
        break;

    case FIRING_WARN:
        break;
        
    case VENTING: {
            for (int i = 0; i < VENT_LED_COUNT; i++) {
                ventLights.setPixelColor(i, ventColour);
            }
            for (int i = 0; i < CYCLO_LED_COUNT; i++) {
                cycloLights.setPixelColor(i, cyclotronOverheat);
            }

            sdBackgroundChannel.stop();
            sdFXChannel.play(sfxVent);
        }
        break;
    
    case MUSIC_MODE:
        pcellLights.clear();
        cycloLights.clear();
        ventLights.clear();
        sdBackgroundChannel.stop();
        sdFXChannel.stop();

        toggleBluetoothModule(bluetoothMode);
        break;

    default:
        break;
    }

    pcellLights.show();
    cycloLights.show();
    ventLights.show();

    stateLastChanged = millis();

    state = newState;
}

unsigned long lastStateUpdate = 0;
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

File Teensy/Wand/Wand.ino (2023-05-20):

/*
 This sketch is designed to run on a Teensy LC in the wand of the proton pack.
*/

#include <ProtonPackCommon.h>
#include <Encoder.h>
#include <avdweb_Switch.h>
#include <TimerEvent.h>
#include <lcdgfx.h>
#include <lcdgfx_gui.h>
#include <nano_engine_v2.h>
#include <nano_gfx_types.h>
#include <Adafruit_NeoPixel.h>
#include <CmdMessenger.h>
#include <HT16K33.h>

/*  ----------------------
	Variables to flip switch directions depending on
	your wiring implementation
----------------------- */
// Use this to flip the rotary switch direction in code
int rotaryDirection = -1;
const bool SW_ACTIVATE_INVERT = false;
const bool SW_LOWER_INVERT = false;
const bool SW_UPPER_INVERT = false;

/*  ----------------------
	Pin & Range Definitions
	: Note that for ranges the indexes are inclusive
----------------------- */
// Switches
const int SW_ACTIVATE_PIN = A3;
const int BTN_INTENSIFY_PIN = A2;
const int SW_LOWER_PIN = A0;
const int SW_UPPER_PIN = A6;
const int BTN_TIP_PIN = 2;
const int ROT_BTN_PIN = 3;
const int ROT_A_PIN = 5;
const int ROT_B_PIN = 6;

// LEDS
const int BARREL_LED_PIN = 22;// A8;
const int BARREL_LED_COUNT=  7;
const int TIP_LED_PIN = 23; // A9;
const int TIP_LED_COUNT = 1;
const int BODY_LED_PIN = 21; // A7;
const int BODY_LED_COUNT = 5;
const int VENT_INDEX = 1;
const int FRONT_INDEX = 0;
const int TOP_FORWARD_INDEX = 2;
const int TOP_BACK_INDEX = 3;
const int SLO_BLO_INDEX = 4;

/*  ----------------------
	Library objects
----------------------- */
// Display setup
DisplaySSD1306_128x32_I2C display(-1);
unsigned long displayIdleTimeout = 10000;
unsigned long lastDisplayUpdate = 0;
bool lastDisplayMove = true;

// Neopixels
Adafruit_NeoPixel barrelLights = Adafruit_NeoPixel(BARREL_LED_COUNT, BARREL_LED_PIN, NEO_GRBW + NEO_KHZ800);
Adafruit_NeoPixel tipLights = Adafruit_NeoPixel(TIP_LED_COUNT, TIP_LED_PIN, NEO_GRBW + NEO_KHZ800);
Adafruit_NeoPixel bodyLights = Adafruit_NeoPixel(BODY_LED_COUNT, BODY_LED_PIN, NEO_GRBW + NEO_KHZ800);

// Bar graph
HT16K33 bargraph = HT16K33();

// Serial Command Controller - Use hardware serial port
CmdMessenger cmdMessenger = CmdMessenger(Serial1);

Encoder ROTARY(ROT_A_PIN, ROT_B_PIN);

Switch actSwitch = Switch(SW_ACTIVATE_PIN);
Switch intButton = Switch(BTN_INTENSIFY_PIN, INPUT_PULLUP, LOW, 50, 1000);
Switch lowerSwitch = Switch(SW_LOWER_PIN);
Switch upperSwitch = Switch(SW_UPPER_PIN);
Switch tipButton = Switch(BTN_TIP_PIN, INPUT_PULLUP, LOW, 50, 1000);
Switch encoderButton = Switch(ROT_BTN_PIN);

/*  ----------------------
	Timers
----------------------- */
TimerEvent bodyTimer;
int bodyPeriod = 25;
TimerEvent tipTimer;
int tipPeriod = 50;
TimerEvent barrelTimer;
int barrelPeriod = 50;

/*  ----------------------
	State control
----------------------- */
int selectedIndex = 0;
displayStates displayState;

State state = OFF;

bool overheatMode = false;
bool bluetoothMode = false;
bool musicPlaying = false;
bool packConnected = false;
int trackNumber = defaultTrack;
unsigned long stateLastChanged = 0;

uint32_t savedTipColour;
unsigned long lastTipChange;
uint32_t savedBodyColours[BODY_LED_COUNT];
unsigned long lastBodyChange[BODY_LED_COUNT];
unsigned long lastBarrelChange;

const float powerDownLEDDecayRate = (float)255 / (0.8 * POWERDOWN_TIME);

const int numFiringLEDColours = 10;
const uint32_t firingLEDColours[numFiringLEDColours] = {
	Adafruit_NeoPixel::Color(0,0,0,0),
	Adafruit_NeoPixel::Color(0,0,255,0),
	Adafruit_NeoPixel::Color(5,0,0,50),
	Adafruit_NeoPixel::Color(0,0,150,0),
	Adafruit_NeoPixel::Color(0,0,0,255),
	Adafruit_NeoPixel::Color(5,0,100,255),
	Adafruit_NeoPixel::Color(0,0,200,100),
	Adafruit_NeoPixel::Color(0,0,5,255),
	Adafruit_NeoPixel::Color(0,0,175,100),
	Adafruit_NeoPixel::Color(0,0,0,50)
};

const int firingBlinkMS = 500;
const int warningBlinkMS = 150;
const int ventFlickerPercentage = 15;
const int batteryIndicatorFadePeriod = 2000;

const uint32_t ventColour = Adafruit_NeoPixel::Color(250, 250, 250, 250);
const uint32_t ventFlickerColour = Adafruit_NeoPixel::Color(0, 0, 250, 100);
const uint32_t tipColour = Adafruit_NeoPixel::Color(0, 0, 0, 100);
const uint32_t frontColour = Adafruit_NeoPixel::Color(200, 200, 200, 200);
const uint32_t topForwardBatteryColour = Adafruit_NeoPixel::Color(0, 0, 25, 0);
const uint32_t topForwardColour = Adafruit_NeoPixel::Color(200, 200, 200, 0);
const uint32_t topBackColour = Adafruit_NeoPixel::Color(0, 0, 0, 100);
const uint32_t sloBloColour = Adafruit_NeoPixel::Color(255, 0, 0, 0);

const int bargraphLEDs = 28;
int bargraphLitCells = 0;
bool bargraphClimbing = true;
const unsigned int bargraphIdlePeriod = 1500;
unsigned int bargraphPeriod = 1500;

unsigned long lastBargraphChange;
int bargraphCache[bargraphLEDs];

const unsigned int bargraphFiringStartPeriod = 1000;
const unsigned int bargraphFiringMinPeriod = 100;
const unsigned int bargraphFiringStopPeriod = 1200;
const int bargraphFiringWidth = 3;
const float bargraphFiringAcceleration = 0.5;

bool firstLoop = true;

void updatePackSettings(unsigned long currentMillis);

/*  ----------------------
	Setup and Loops
----------------------- */
void setup() {
	unsigned long currentMillis = millis();

	// Initialise Serial for Debug + Pack Connection
	Serial.begin(9600);
	Serial1.begin(9600);

	DEBUG_SERIAL.println("Starting Setup");

	// Initialise the display
	display.setFixedFont(ssd1306xled_font6x8);
	display.begin();
	displayBoot(currentMillis);

	// Initialise the pack serial
	cmdMessenger.printLfCr();
	attachCmdMessengerCallbacks();

	// Initialise LEDs and Timers
	barrelLights.begin();
	tipLights.begin();
	bodyLights.begin();
	//delay(250);
	
	tipLights.clear();
	bodyLights.clear();
	barrelLights.clear();

	barrelLights.show();
	bodyLights.show();
	tipLights.show();

	bodyInit(currentMillis);
	bodyTimer.set(bodyPeriod, bodyUpdate);
	barrelInit(currentMillis);
	barrelTimer.set(barrelPeriod, barrelUpdate);
	tipInit(currentMillis);
	tipTimer.set(tipPeriod, tipUpdate);

	// Set up the bar graph
	graphInit(currentMillis);
	
	// Initiate the input switches
	setupInputs();
	
	DEBUG_SERIAL.println("Setup Complete");
	display.clear();
	displayState = DISPLAY_OFF;

	stateLastChanged = currentMillis;
}

// Tracker time to space out checks for pack connection
unsigned long lastPackCheck = millis();
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

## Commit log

2022-07-26 Pin definitions
2022-07-26 Basic state management for switches
2022-07-28 Audio Switching On Sliders
2023-01-13 Audio files initial setup for Teensy deployment
2023-01-13 Project setup for Teensy
2023-01-15 Basic Button Handling
2023-02-26 Updated PIN definitions to match PCBs
2023-03-26 Switches for Wand
2023-04-06 Wand event handlers for serial, button handling
2023-04-08 Booting animations for Power Cell
2023-04-10 Audio naming tweaks, fix to indexing on power cell, new music mode pack effects
    [Pack.ino, ProtonPackCommon.h, Wand.ino]
2023-04-12 Gamme correction for colour transitions to make them smoother
    [Pack.ino, ProtonPackCommon.h, Wand.ino]
2023-04-12 Fixed pack transitions to idle from firing stop, and 5xslowdown to firing stop
    [Pack.ino]
2023-04-12 Fix to flash on vent (had multiplier backwards)
    [Pack.ino, ProtonPackCommon.h]
2023-04-12 Fix to cyclotron transition from boot to idle to avoid instant off of lamps
    [Pack.ino]
2023-04-12 Moved displaystates enum definition to common header to get rid of annoying intellisense error
    [ProtonPackCommon.h, Wand.ino]
2023-04-12 Removed some leftover debug messaging that was causing noise
    [Pack.ino]
2023-04-12 Power Cell Music Mode tweaks - colour distribution, multipliers, min/max
2023-04-12 Changed powercell routine to go to full blank when scrolling. Added booting animation for bargraph
2023-04-13 Documentation: Some placeholders left in BOM
2023-04-14 Donation buttons for github
2023-04-14 Buttons on README.md
2023-04-24 Updated README.md and added folder for STLs
    [Rear Box OLED Lid.stl]
2023-04-24 STL fixes
    [AmpMount.stl, BTMount.stl, RearBoxOLEDLid.stl]
2023-04-24 Finished the BOM (as much as I cba to right now)
2023-05-02 Notes on LED lenses
2023-05-06 Changed LED colours to match lens shades. Added default volume load to Bluetooth idle mode. Changed pack knob to control volume when held. Reduced maximum powercell index so it will always show a bit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
    [Pack.ino, Wand.ino]
2023-05-06 Made battery on indicator pulse
2023-05-06 Added ability to customise the overheat/warning times, and lowered the default setting. This setting can be saved to SD.
    [Pack.ino, ProtonPackCommon.h, Wand.ino]
2023-05-07 Zoom pack PCB photo
2023-05-13 Added PCB schematic printouts as interim until I can remake PCBs in a more open application
2023-05-20 A slightly modified rear box lid which really pushes where you can fit the 128x32 OLED as much to the right as possible without changing the existing rear box design.
    [RearBoxOLEDLid.stl]
2023-05-20 Base plate modified for current PCBs - future versions should make unnecessary. Adjust holes to suit your own needs
    [BasePlate.stl]
